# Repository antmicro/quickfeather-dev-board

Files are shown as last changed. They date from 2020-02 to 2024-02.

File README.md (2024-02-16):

# QuickFeather Development Board

Copyright (c) 2019-2024 [Antmicro](https://www.antmicro.com)

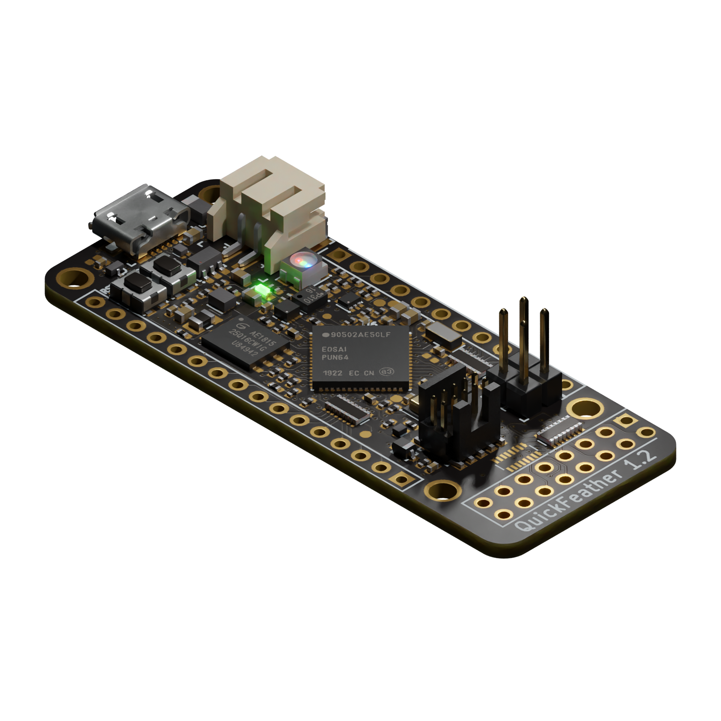
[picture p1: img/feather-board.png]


## Overview

This project contains open hardware design files for the [QuickFeather development board](https://www.quicklogic.com/products/eos-s3/quickfeather-development-kit/) based on the QuickLogic [EOS S3 Sensor Processing Platform](https://www.quicklogic.com/products/eos-s3/).
The design files were created by [Antmicro](https://www.antmicro.com) in cooperation with [QuickLogic](https://www.quicklogic.com/).
The board has been designed to keep compatibility with the [Adafruit Feather](https://learn.adafruit.com/adafruit-feather/feather-specification) ecosystem of evaluation boards.
This allows the user to explore functionalities of the EOS S3 platform.

### Project structure:

The main directory contains the KiCad design files, LICENSE and README.
The remaining files are stored in the following directories:

* ``img`` - contains graphics for this README
* ``doc`` - contains generated schematics and other documentation
* ``lib`` - contains KiCad component library

## Key features

* QuickLogic EOS S3 Processing Platform
* [mCube MC3635](https://www.memsic.com/Public/Uploads/uploadfile/files/20220119/MC3635Datasheet.pdf) accelerometer
* [Infineon DPS310](https://www.infineon.com/dgdl/Infineon-DPS310-DataSheet-v01_01-EN.pdf?fileId=5546d462576f34750157750826c42242) pressure sensor
* [Infineon IM69D130](https://www.infineon.com/dgdl/Infineon-IM69D130-DS-v01_00-EN.pdf?fileId=5546d462602a9dc801607a0e46511a2e) MEMS microphone 
* 16Mbit of on-board [flash memory](https://www.gigadevice.com.cn/Public/Uploads/uploadfile/files/20220714/DS-00086-GD25Q16C-Rev3.2.pdf)
* User button and RGB LED
* Powered from USB or a single Li-Po battery
* Integrated [battery charger](http://ww1.microchip.com/downloads/en/DeviceDoc/20001984g.pdf)
* USB data signals tied to programmable logic
* IO signals break-routed into general purpose pinheads
* Compatible with standard 0.1" breadboards

## Development ecosystem

### Simulation

The board is supported in [Renode](https://renode.io/), the open source simulation framework by Antmicro - you can run a virtual copy of this hardware for software development purposes on your PC. A link to the relevant demo script is provided in Renode's [supported boards section](https://renode.readthedocs.io/en/latest/introduction/supported-boards.html).

## License

This project is licensed under the [CC BY-SA 4.0 DEED](LICENSE) license.

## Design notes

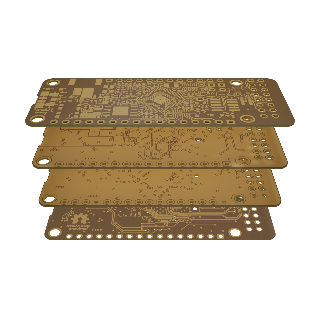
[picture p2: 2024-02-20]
assets/previews/layer1_thumbnail.webp

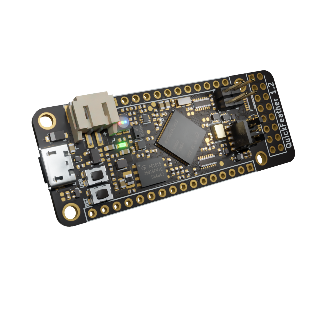
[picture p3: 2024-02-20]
assets/previews/leftT_thumbnail.png

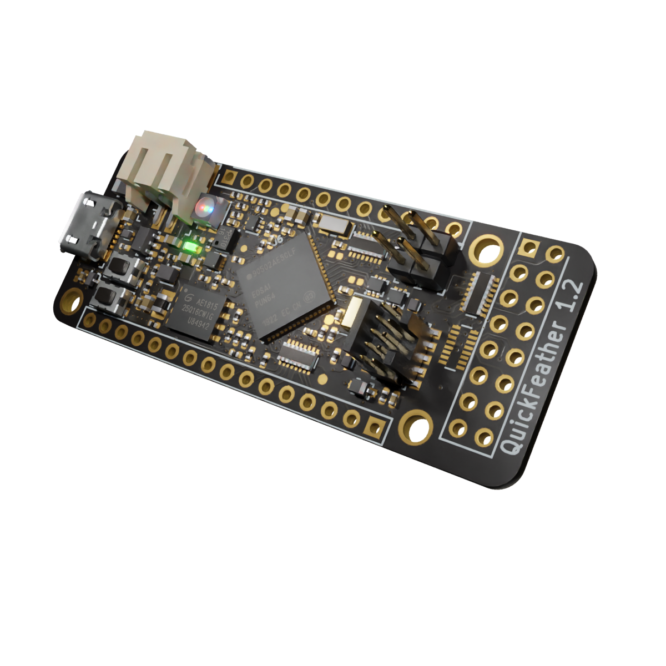
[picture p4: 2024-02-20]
assets/previews/rightT.webp

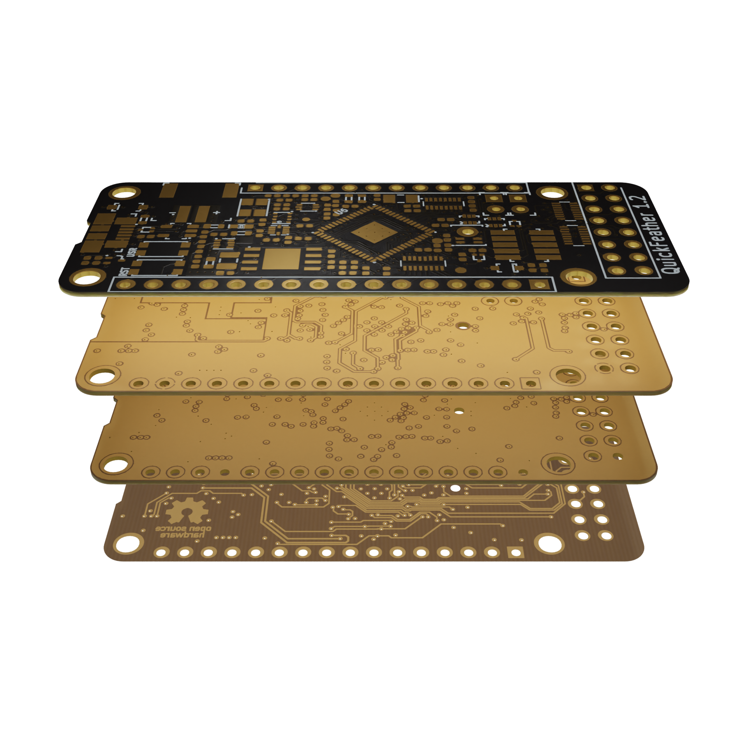
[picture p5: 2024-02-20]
assets/previews/stackup.png

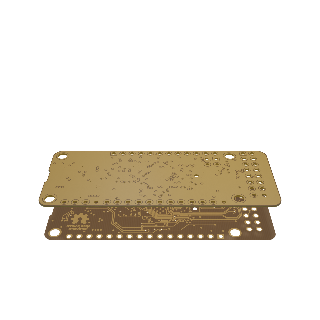
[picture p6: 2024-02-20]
assets/previews/layer3_thumbnail.webp

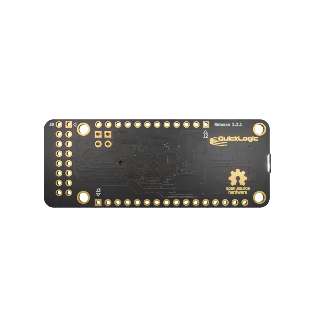
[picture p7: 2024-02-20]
assets/previews/orthoB_thumbnail.webp

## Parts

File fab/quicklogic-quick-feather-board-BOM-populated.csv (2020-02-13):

Reference | Quantity | Value | Footprint | Manufacturer | MPN
C1 C14 C16 C2 C5 | 5 | C_4u7_0603 | 0603-cap | TDK | C1608X5R1V475M080AC
C10 C11 C12 C13 C15 C17 C18 C8 C9 | 9 | C_100n_0402_6V3 | 0402-cap | Walsin | 0402X104K6R3CT
C3 | 1 | C_100p_0402 | 0402-cap | WALSIN | 0402N101J500CT
C4 | 1 | C_22u_0603 | 0603-cap | MURATA | GRM188R60J226MEA0D
C6 C7 | 2 | C_12p_0402 | 0402-cap | TDK | CGA2B2C0G1H120J050BA
D1 | 1 | MBR0520LT1G | SOD-123 | ON Semiconductor | MBR0520LT1G
D11 D3 D5 | 3 | TPD2EUSB30DRTR | SOT-3 | Texas Instruments | TPD2EUSB30DRTR
D2 | 1 | LG_L29K-G2J1-24-Z | LED_0603 | OSRAM Opto Semiconductors Inc. | LG L29K-G2J1-24-Z
D4 | 1 | ASMB-MTB1-0A3A2 | LED-PLCC4_3.2x2.8mm_B | Broadcom | ASMB-MTB1-0A3A2
D6 | 1 | SD05C.TCT | SOD-323-SD05 | Semtec | SD05C.TCT
IC1 | 1 | EOS-S3-QFN | QFN-64_8.5x8.5_EOS |  |  | Delivered by Quicklogic
J1 J7 | 2 | 61300211121 | PinHeader_1x2_P2.54_Drill0.9mm | Wurth Electronic | 61300211121
J4 | 1 | S2B-PH-SM4-TB_LF__SN_ | PinHeader_2x1mm_P2mm_SMD_RA | JST Sales America Inc. | S2B-PH-SM4-TB(LF)(SN)
J5 | 1 | 0473460001 | USB_Micro_B_Female_0473460001 | Molex | 0473460001
J6 | 1 | FTSH-105-01-L-DV-K | PinHeader_2x5_P1.27_SMD | Samtec Inc. | FTSH-105-01-L-DV-K
L1 | 1 | DFE201610E-R47M=P2 | 0806 | Murata | DFE201610E-R47M=P2
MIC1 | 1 | IM69D130 | IM69D130 | Infineon | IM69D130
Q1 | 1 | NX3008CBKV | SOT-563 | Nexperia | NX3008CBKV
Q2 Q3 | 2 | 2N7002PV | SOT-563 | Nexperia | 2N7002PV
R1 R12 R17 R5 | 4 | R_100k_0402 | 0402-res | VISHAY | CRCW0402100KFKEDHP
R10 R14 R15 R19 R23 R31 R32 R34 R37 R6 R8 | 11 | R_10k_0402 | 0402-res | VISHAY | CRCW040210K0FKEDHP
R11 R28 R29 R38 R39 R40 R7 | 7 | R_22R_0402 | 0402-res | VISHAY | CRCW040222R0FKED
R13 R24 R26 | 3 | R_100R_0402 | 0402-res | BOURNS | CR0402-FX-1000GLF
R16 | 1 | R_200k_0402 | 0402-res | YAGEO_(PHYCOMP) | RC0402FR-07200KL
R18 R2 R20 | 3 | R_4k7_0402 | 0402-res | PANASONIC_ELECTRONIC_COMPONENTS | ERJ2GEJ472X
R25 | 1 | R_220R_0402 | 0402-res | Stackpole Electronics Inc | RMCF0402JT220R
R3 R9 | 2 | R_1k5_0402 | 0402-res | PANASONIC_ELECTRONIC_COMPONENTS | ERJ2RKF1501X
R30 R33 R41 | 3 | EXB2HV220JV | R_Array_Convex_8x0602 | Panasonic | EXB2HV220JV
R4 | 1 | R_453k_0402 | 0402-res | VISHAY | CRCW0402453KFKED
S1 S2 | 2 | KMR2 | SW_SPST_4.2x2.8 | C&K Components | KMR211NGLFS
U1 | 1 | TPS62821DLCR | QFN-8_2x1mm | Texas Instruments | TPS62821DLCR
U2 | 1 | MCP73831T-2ACI_OT | SOT-753 | Microchip Technology | MCP73831T-2ACI/OT
U3 | 1 | GD25Q16CWIGR | GD25Q16CWIG | GigaDevice | GD25Q16CWIGR
U4 | 1 | DPS310 | PG-VLGA-8-2 | Infineon | DPS310
U5 | 1 | MC3635 | MC3635 | mCube | MC3635
X1 | 1 | ECS-_327-12_5-34B-TR | SMD-2_3.2x1.5mm | ECS Inc. | ECS-.327-12.5-34B-TR

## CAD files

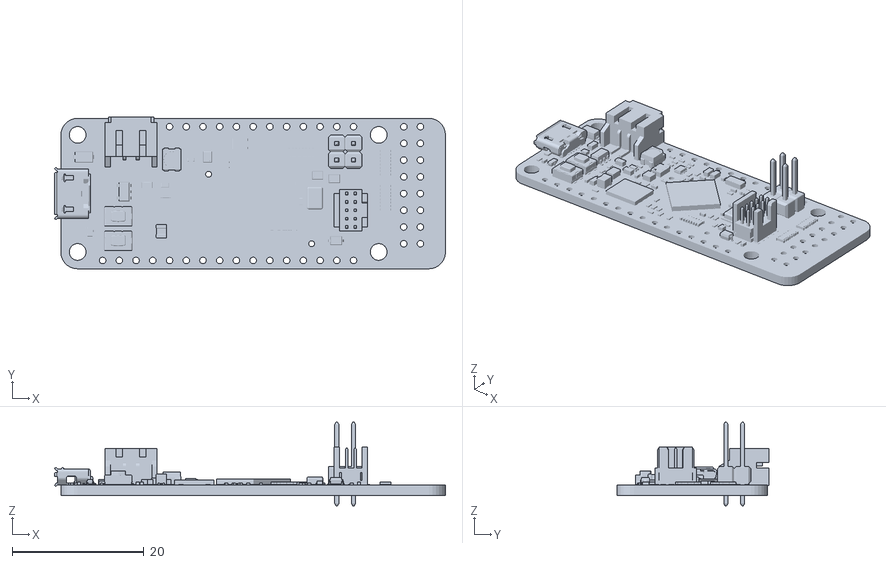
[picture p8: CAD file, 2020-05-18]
3d-model/quickfeather-board.stl
59.4 x 23.0 x 12.7

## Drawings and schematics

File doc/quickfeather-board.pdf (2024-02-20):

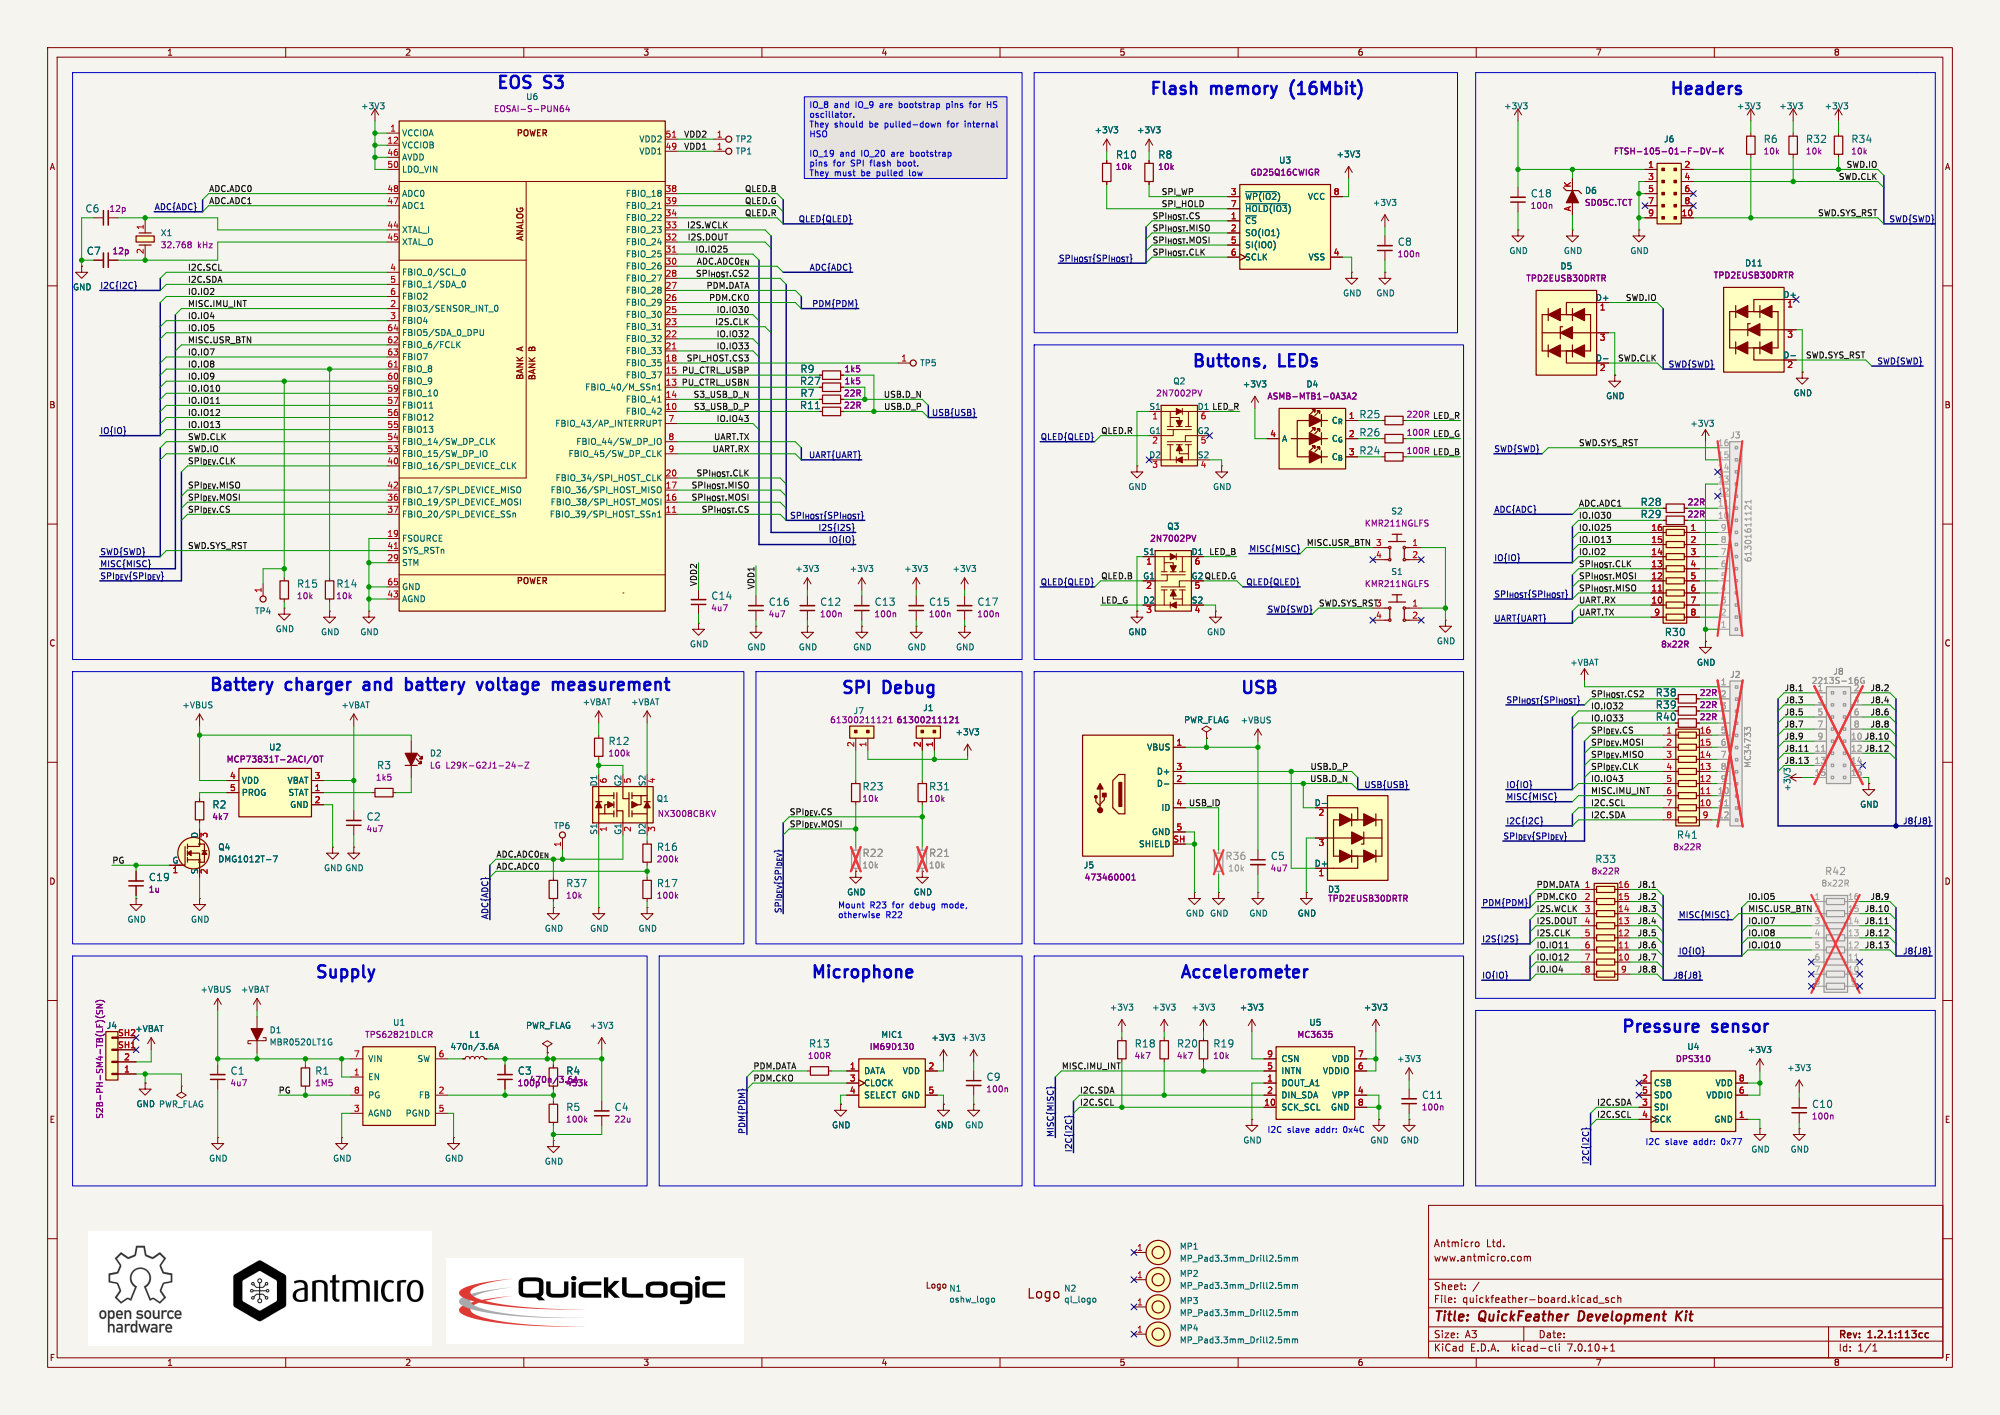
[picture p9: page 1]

IO_19 and IO_20 are bootstrap
pins for SPI flash boot. They must be pulled low

USB.D_P USB{USB} USB.D_N

SPI_{HOST}{SPI_{HOST}} ADC.ADC1 SPI_{HOST}.CLK
J8.7 ADC{ADC}

ID 4 GND 5 SHIELD SH

Id: 1/1 Title: QuickFeather Development Kit File: quickfeather-board.kicad_sch Sheet: / www.antmicro.com

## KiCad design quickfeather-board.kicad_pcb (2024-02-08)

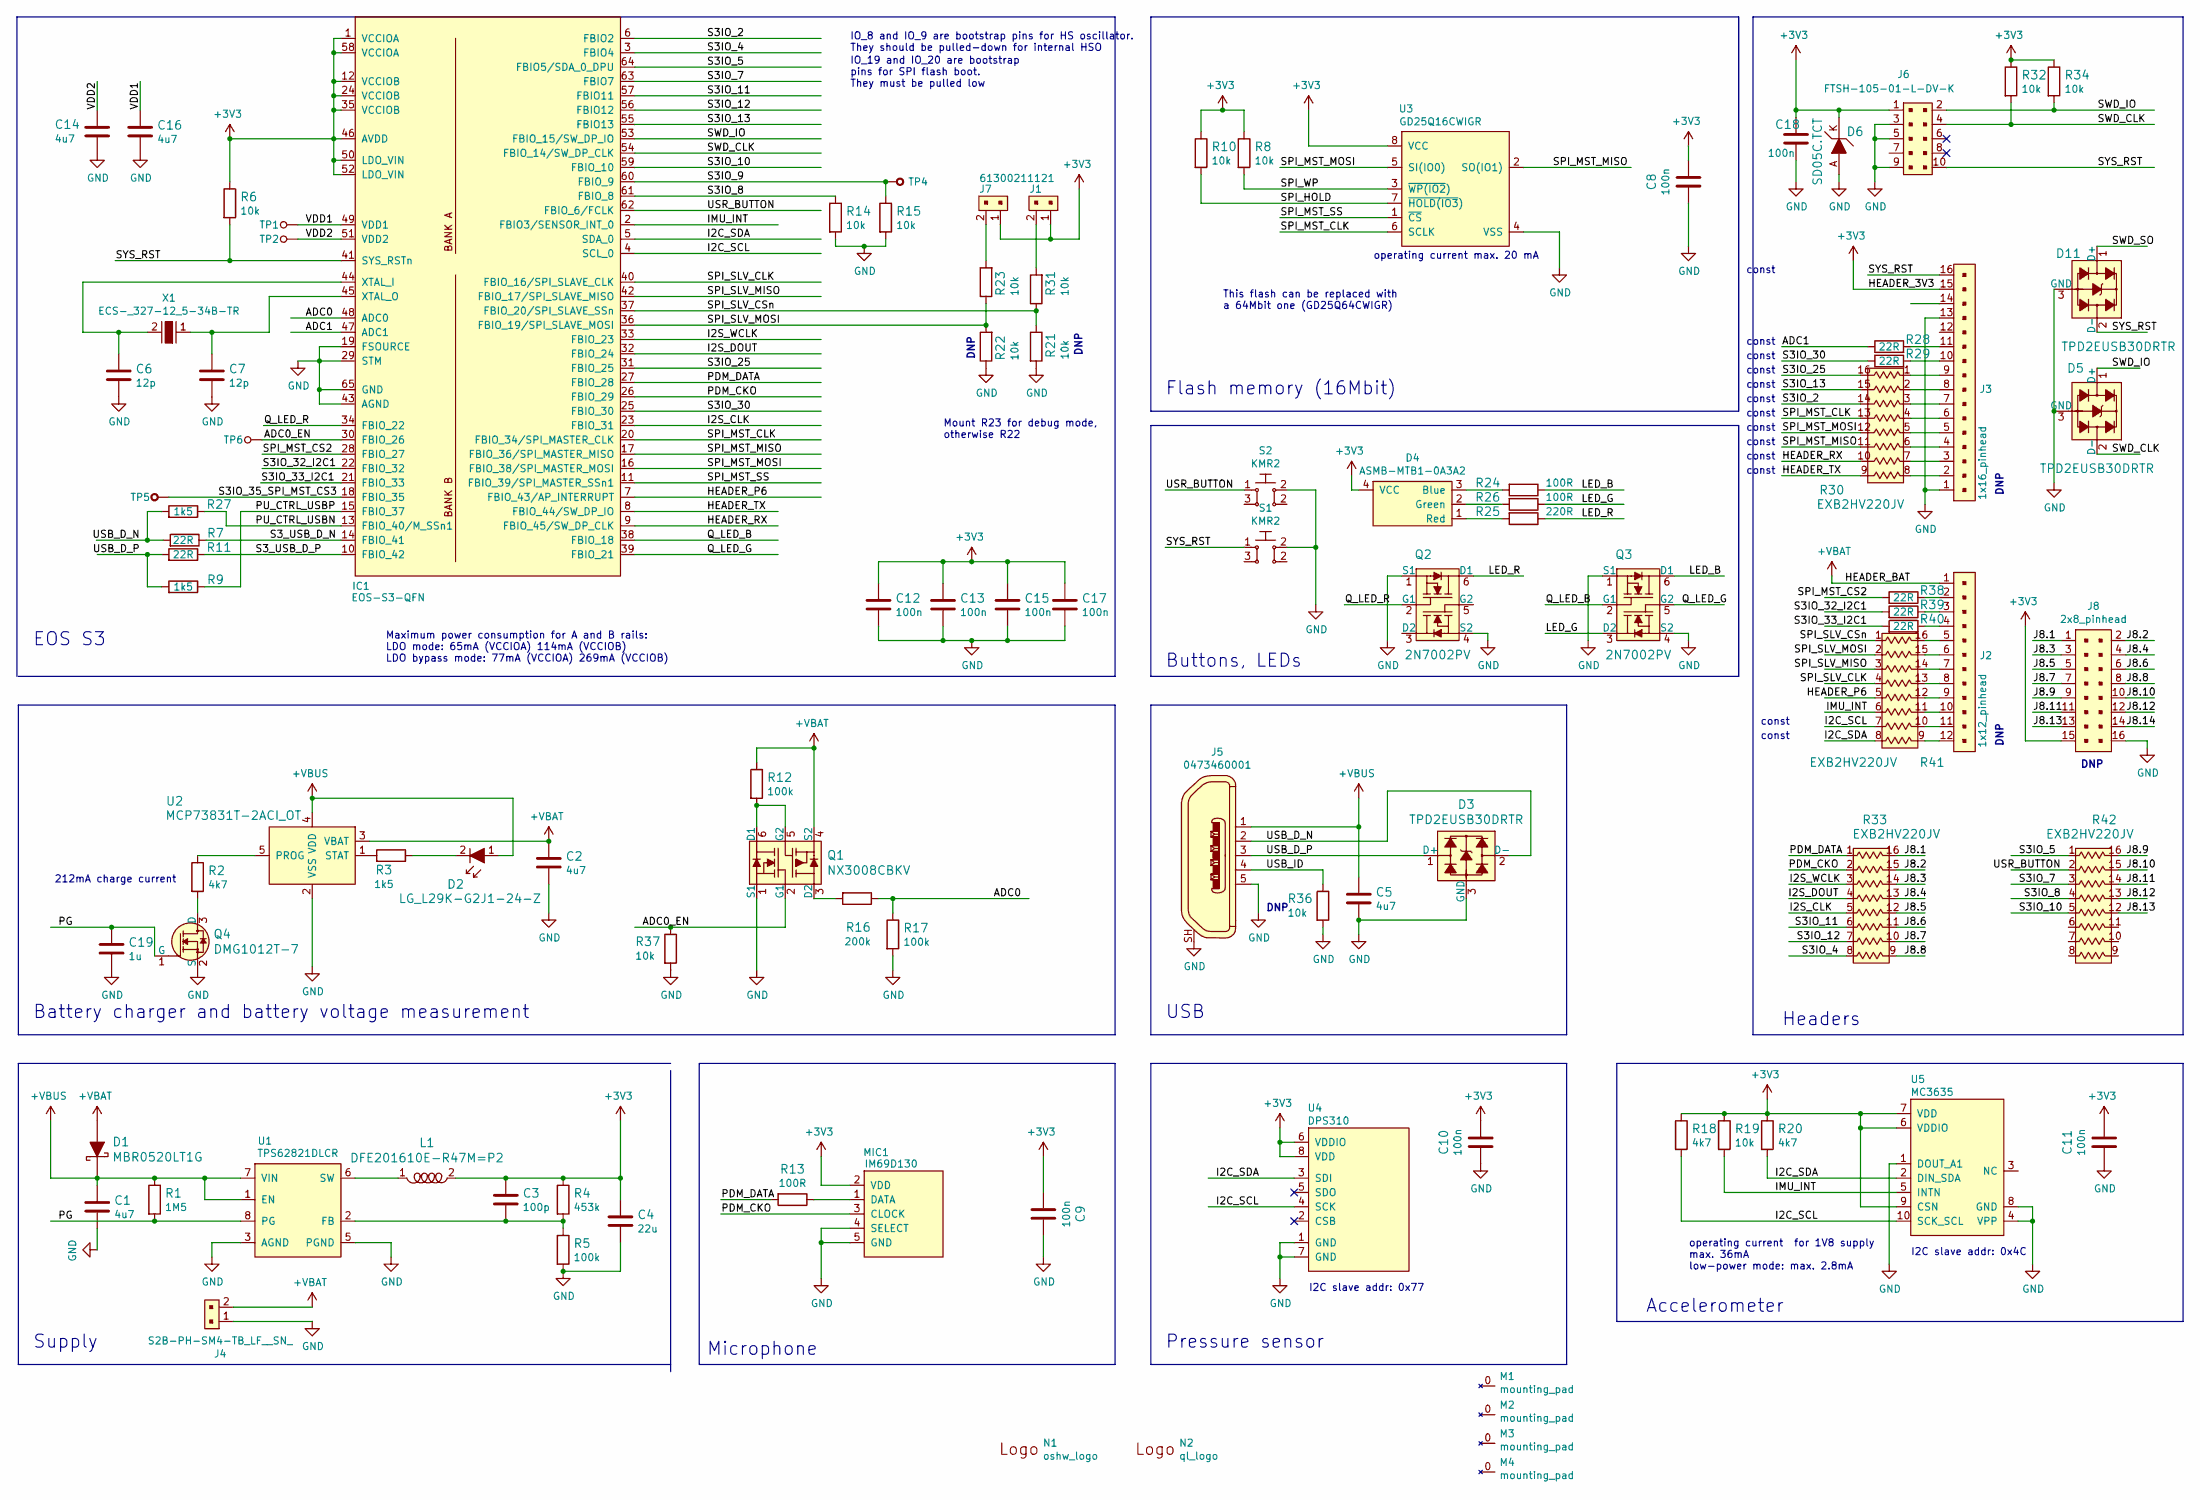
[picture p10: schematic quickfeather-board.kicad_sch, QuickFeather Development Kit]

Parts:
C1, C2, C5, C14, C16: C_4u7_0603; 0603-cap; MPN C1608X5R1V475M080AC
C3: C_100p_0402; 0402-cap; MPN 0402N101J500CT
C4: C_22u_0603; 0603-cap; MPN GRM188R60J226MEA0D
C6, C7: C_12p_0402; 0402-cap; MPN CGA2B2C0G1H120J050BA
C8, C9, C10, C11, C12, C13, C15, C17, C18: C_100n_0402_6V3; 0402-cap; MPN 0402X104K6R3CT
C19: C_1u_0402; 0402-cap; MPN C1005X6S1A105K050BC
D1: MBR0520LT1G; SOD-123; MPN MBR0520LT1G
D2: LG_L29K-G2J1-24-Z; LED_0603; MPN LG L29K-G2J1-24-Z
D3, D5, D11: TPD2EUSB30DRTR; SOT-3; MPN TPD2EUSB30DRTR
D4: ASMB-MTB1-0A3A2; LED-PLCC4_3.2x2.8mm_B; MPN UHD1110-FKA
D6: SD05C.TCT; SOD-323-SD05; MPN SD05C.TCT
IC1: EOS-S3-QFN; QFN-64_8.5x8.5_EOS; MPN EOSA1-S-PUN64
J1, J7: 61300211121; PinHeader_1x2_P2.54_Drill0.9mm; MPN 61300211121
J2: 1x12_pinhead; MPN MC34733
J3: 1x16_pinhead; MPN 61301611121
J4: S2B-PH-SM4-TB_LF__SN_; PinHeader_2x1mm_P2mm_SMD_RA; MPN S2B-PH-SM4-TB(LF)(SN)
J5: 0473460001; USB_Micro_B_Female_0473460001; MPN 0473460001
J6: FTSH-105-01-L-DV-K; PinHeader_2x5_P1.27_SMD; MPN FTSH-105-01-L-DV-K
J8: 2x8_pinhead; MPN 2213S-16G
L1: DFE201610E-R47M=P2; 0806; MPN DFE201610E-R47M=P2
M1, M2, M3, M4: mounting_pad; MPAD
MIC1: IM69D130; MPN IM69D130
N1: oshw_logo; oshw-logo
N2: ql_logo; LOGO
Q1: NX3008CBKV; SOT-563; MPN NX3008CBKV
Q2, Q3: 2N7002PV; SOT-563; MPN 2N7002PV
Q4: DMG1012T-7; SOT-523; MPN DMG1012T-7
R1: R_1M5_0402; 0402-res; MPN MCWR04W1504FTL
R2, R18, R20: R_4k7_0402; 0402-res; MPN ERJ2GEJ472X
R3, R9, R27: R_1k5_0402; 0402-res; MPN ERJ2RKF1501X
R4: R_453k_0402; 0402-res; MPN CRCW0402453KFKED
R5, R12, R17: R_100k_0402; 0402-res; MPN CRCW0402100KFKEDHP
R6, R8, R10, R14, R15, R19, R21, R22, R23, R31, R32, R34, R36, R37: R_10k_0402; 0402-res; MPN CRCW040210K0FKEDHP
R7, R11, R28, R29, R38, R39, R40: R_22R_0402; 0402-res; MPN CRCW040222R0FKED
R13, R24, R26: R_100R_0402; 0402-res; MPN CR0402-FX-1000GLF
R16: R_200k_0402; 0402-res; MPN RC0402FR-07200KL
R25: R_220R_0402; 0402-res; MPN RMCF0402JT220R
R30, R33, R41, R42: EXB2HV220JV; R_Array_Convex_8x0602; MPN EXB2HV220JV
S1, S2: KMR2; SW_SPST_4.2x2.8; MPN KMR211NGLFS
TP1, TP2, TP6: TP_SMD1MM; Testpoint_smd_1mm; MPN N/A
TP4, TP5: TP_THT; Testpoint_THT_Drill0.9mm; MPN N/A
U1: TPS62821DLCR; QFN-8_2x1mm; MPN TPS62821DLCR
U2: MCP73831T-2ACI_OT; SOT-753; MPN MCP73831T-2ACI/OT
U3: GD25Q16CWIGR; GD25Q16CWIG; MPN GD25Q16CWIGR
U4: DPS310; PG-VLGA-8-2; MPN DPS310
U5: MC3635; MPN MC3635
X1: ECS-_327-12_5-34B-TR; SMD-2_3.2x1.5mm; MPN ECS-.327-12.5-34B-TR

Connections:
+3V3: C3.1, C4.1, C8.1, C9.2, C10.1, C11.1, C12.1, C13.1, C15.1, C17.1, C18.1, D4.4 (VCC), D6.K, IC1.1 (VCCIOA), IC1.12 (VCCIOB), IC1.24 (VCCIOB), IC1.35 (VCCIOB), IC1.46 (AVDD), IC1.50 (LDO_VIN), IC1.52 (LDO_VIN), IC1.58 (VCCIOA), J1.1, J3.15, J6.1, J7.1, J8.15, L1.2, MIC1.2 (VDD), R4.1, R6.1, R8.1, R10.1, R18.1, R19.1, R20.1, R32.1, R34.1, U3.8 (VCC), U4.6 (VDDIO), U4.8 (VDD), U5.6 (VDDIO), U5.7 (VDD), U5.9 (CSN)
+VBAT: C2.1, D1.A, J2.1, J4.2, Q1.4 (S2), R12.1, U2.3 (VBAT)
+VBUS: C1.1, C5.1, D1.K, D2.1, J5.1, R1.1, U1.1 (EN), U1.7 (VIN), U2.4 (VDD)
/ADC0: IC1.48 (ADC0), R16.1, R17.1
/ADC0_EN: IC1.30 (FBIO_26), Q1.2 (G1), R37.1, TP6.1
/ADC1: IC1.47 (ADC1), R28.1
/HEADER_P6: IC1.7 (FBIO_43/AP_INTERRUPT), R41.5
/HEADER_RX: IC1.9 (FBIO_45/SW_DP_CLK), R30.10
/HEADER_TX: IC1.8 (FBIO_44/SW_DP_IO), R30.9
/I2C_SCL: IC1.4 (SCL_0), R18.2, R41.7, U4.4 (SCK), U5.10 (SCK_SCL)
/I2C_SDA: IC1.5 (SDA_0), R20.2, R41.8, U4.3 (SDI), U5.2 (DIN_SDA)
/I2S_CLK: IC1.23 (FBIO_31), R33.5
/I2S_DOUT: IC1.32 (FBIO_24), R33.4
/I2S_WCLK: IC1.33 (FBIO_23), R33.3
/IMU_INT: IC1.2 (FBIO3/SENSOR_INT_0), R19.2, R41.6, U5.5 (INTN)
/J8.1: J8.1, R33.16
/J8.2: J8.2, R33.15
/J8.3: J8.3, R33.14
/J8.4: J8.4, R33.13
/J8.5: J8.5, R33.12
/J8.6: J8.6, R33.11
/J8.7: J8.7, R33.10
/J8.8: J8.8, R33.9
/J8.9: J8.9, R42.16
/J8.10: J8.10, R42.15
/J8.11: J8.11, R42.14
/J8.12: J8.12, R42.13
/J8.13: J8.13, R42.12
/J8.14: J8.14
/LED_B: Q3.6 (D1), R24.1
/LED_G: Q3.3 (D2), R26.1
/LED_R: Q2.6 (D1), R25.1
/PDM_CKO: IC1.26 (FBIO_29), MIC1.3 (CLOCK), R33.2
/PDM_DATA: IC1.27 (FBIO_28), R13.2, R33.1
/PG: C19.1, Q4.1 (G), R1.2, U1.8 (PG)
/PU_CTRL_USBN: IC1.13 (FBIO_40/M_SSn1), R27.1
/PU_CTRL_USBP: IC1.15 (FBIO_37), R9.1
/Q_LED_B: IC1.38 (FBIO_18), Q3.2 (G1)
/Q_LED_G: IC1.39 (FBIO_21), Q3.5 (G2)
/Q_LED_R: IC1.34 (FBIO_22), Q2.2 (G1)
/S3IO_2: IC1.6 (FBIO2), R30.14
/S3IO_4: IC1.3 (FBIO4), R33.8
/S3IO_5: IC1.64 (FBIO5/SDA_0_DPU), R42.1
/S3IO_7: IC1.63 (FBIO7), R42.3
/S3IO_8: IC1.61 (FBIO_8), R14.1, R42.4
/S3IO_9: IC1.60 (FBIO_9), R15.1, TP4.1
/S3IO_10: IC1.59 (FBIO_10), R42.5
/S3IO_11: IC1.57 (FBIO11), R33.6
/S3IO_12: IC1.56 (FBIO12), R33.7
/S3IO_13: IC1.55 (FBIO13), R30.15
/S3IO_25: IC1.31 (FBIO_25), R30.16
/S3IO_30: IC1.25 (FBIO_30), R29.1
/S3IO_32_I2C1: IC1.22 (FBIO_32), R39.2
/S3IO_33_I2C1: IC1.21 (FBIO_33), R40.2
/S3IO_35_SPI_MST_CS3: IC1.18 (FBIO_35), TP5.1
/S3_USB_D_N: IC1.14 (FBIO_41), R7.1
/S3_USB_D_P: IC1.10 (FBIO_42), R11.1
/SPI_HOLD: R10.2, U3.7 (~HOLD(IO3))
/SPI_MST_CLK: IC1.20 (FBIO_34/SPI_MASTER_CLK), R30.13, U3.6 (SCLK)
/SPI_MST_CS2: IC1.28 (FBIO_27), R38.2
/SPI_MST_MISO: IC1.17 (FBIO_36/SPI_MASTER_MISO), R30.11, U3.2 (SO(IO1))
/SPI_MST_MOSI: IC1.16 (FBIO_38/SPI_MASTER_MOSI), R30.12, U3.5 (SI(IO0))
/SPI_MST_SS: IC1.11 (FBIO_39/SPI_MASTER_SSn1), U3.1 (~CS)
/SPI_SLV_CLK: IC1.40 (FBIO_16/SPI_SLAVE_CLK), R41.4
/SPI_SLV_CSn: IC1.37 (FBIO_20/SPI_SLAVE_SSn), R21.1, R31.1, R41.1
/SPI_SLV_MISO: IC1.42 (FBIO_17/SPI_SLAVE_MISO), R41.3
/SPI_SLV_MOSI: IC1.36 (FBIO_19/SPI_SLAVE_MOSI), R22.2, R23.1, R41.2
/SPI_WP: R8.2, U3.3 (~WP(IO2))
/SWD_CLK: D5.2 (D-), IC1.54 (FBIO_14/SW_DP_CLK), J6.4, R32.2
/SWD_IO: D5.1 (D+), IC1.53 (FBIO_15/SW_DP_IO), J6.2, R34.2
/SWD_SO: D11.1 (D+)
/SYS_RST: D11.2 (D-), IC1.41 (SYS_RSTn), J3.16, J6.10, R6.2, S1.1
/USB_D_N: D3.2 (D-), J5.2, R7.2, R27.2
/USB_D_P: D3.1 (D+), J5.3, R9.2, R11.2
/USB_ID: J5.4, R36.1
/USR_BUTTON: IC1.62 (FBIO_6/FCLK), R42.2, S2.1
/VDD1: C16.1, IC1.49 (VDD1), TP1.1
/VDD2: C14.1, IC1.51 (VDD2), TP2.1
GND: C1.2, C2.2, C4.2, C5.2, C6.2, C7.2, C8.2, C9.1, C10.2, C11.2, C12.2, C13.2, C14.2, C15.2, C16.2, C17.2, C18.2, C19.2, D3.3 (GND), D5.3 (GND), D6.A, D11.3 (GND), IC1.19 (FSOURCE), IC1.29 (STM), IC1.43 (AGND), IC1.65 (GND), J3.1, J3.13, J4.1, J5.5, J5.SH, J6.3, J6.5, J6.9, J8.16, MIC1.4 (SELECT), MIC1.5 (GND), Q1.1 (S1), Q2.1 (S1), Q2.4 (S2), Q3.1 (S1), Q3.4 (S2), Q4.2 (S), R5.2, R14.2, R15.2, R17.2, R21.2, R22.1, R36.2, R37.2, S1.2, S2.2, U1.3 (AGND), U1.5 (PGND), U2.2 (VSS), U3.4 (VSS), U4.1 (GND), U4.7 (GND), U5.1 (DOUT_A1), U5.4 (VPP), U5.8 (GND)
unnamed: C3.2, R4.2, R5.1, U1.2 (FB)
unnamed: C6.1, IC1.44 (XTAL_I), X1.2
unnamed: C7.1, IC1.45 (XTAL_O), X1.1
unnamed: D2.2, R3.1
unnamed: D4.1 (Red), R25.2
unnamed: D4.2 (Green), R26.2
unnamed: D4.3 (Blue), R24.2
unnamed: J1.2, R31.2
unnamed: J2.2, R38.1
unnamed: J2.3, R39.1
unnamed: J2.4, R40.1
unnamed: J2.5, R41.16
unnamed: J2.6, R41.15
unnamed: J2.7, R41.14
unnamed: J2.8, R41.13
unnamed: J2.9, R41.12
unnamed: J2.10, R41.11
unnamed: J2.11, R41.10
unnamed: J2.12, R41.9
unnamed: J3.2, R30.8
unnamed: J3.3, R30.7
unnamed: J3.4, R30.6
unnamed: J3.5, R30.5
unnamed: J3.6, R30.4
unnamed: J3.7, R30.3
unnamed: J3.8, R30.2
unnamed: J3.9, R30.1
unnamed: J3.10, R29.2
unnamed: J3.11, R28.2
unnamed: J7.2, R23.2
unnamed: L1.1, U1.6 (SW)
unnamed: MIC1.1 (DATA), R13.1
unnamed: Q1.3 (D2), R16.2
unnamed: Q1.5 (G2), Q1.6 (D1), R12.2
unnamed: Q4.3 (D), R2.2
unnamed: R2.1, U2.5 (PROG)
unnamed: R3.2, U2.1 (STAT)

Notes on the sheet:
Battery charger and battery voltage measurement
const
Pressure sensor
DNP
operating current max. 20 mA
USB
IO_19 and IO_20 are bootstrap pins for SPI flash boot. They must be pulled low
Supply
Microphone
Headers
This flash can be replaced with a 64Mbit one (GD25Q64CWIGR)
212mA charge current
EOS S3
I2C slave addr: 0x4C
I2C slave addr: 0x77
Flash memory (16Mbit)
Buttons, LEDs
Mount R23 for debug mode, otherwise R22
Maximum power consumption for A and B rails: LDO mode: 65mA (VCCIOA) 114mA (VCCIOB) LDO bypass mode: 77mA (VCCIOA) 269mA (VCCIOB)
IO_8 and IO_9 are bootstrap pins for HS oscillator. They should be pulled-down for internal HSO
Accelerometer
operating current for 1V8 supply max. 36mA low-power mode: max. 2.8mA

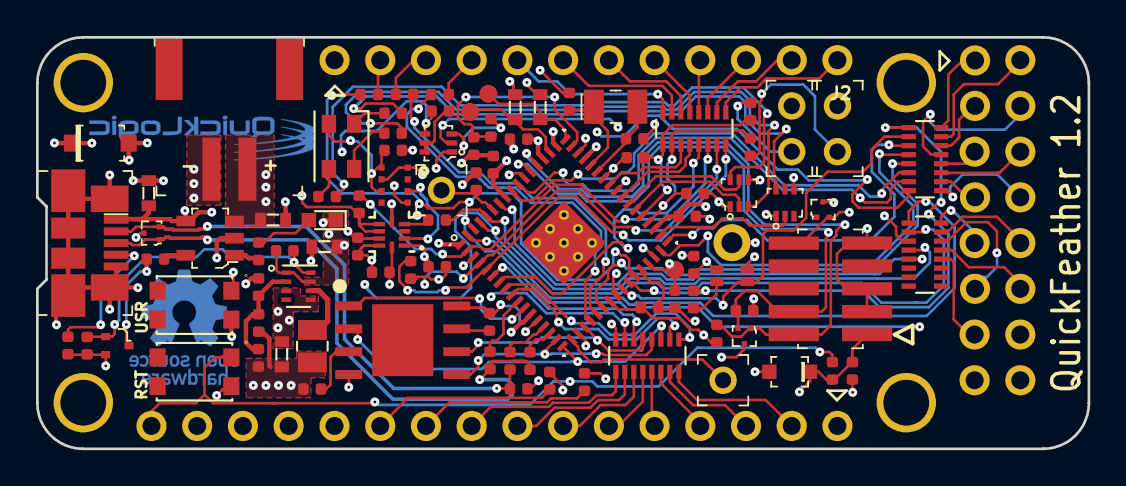
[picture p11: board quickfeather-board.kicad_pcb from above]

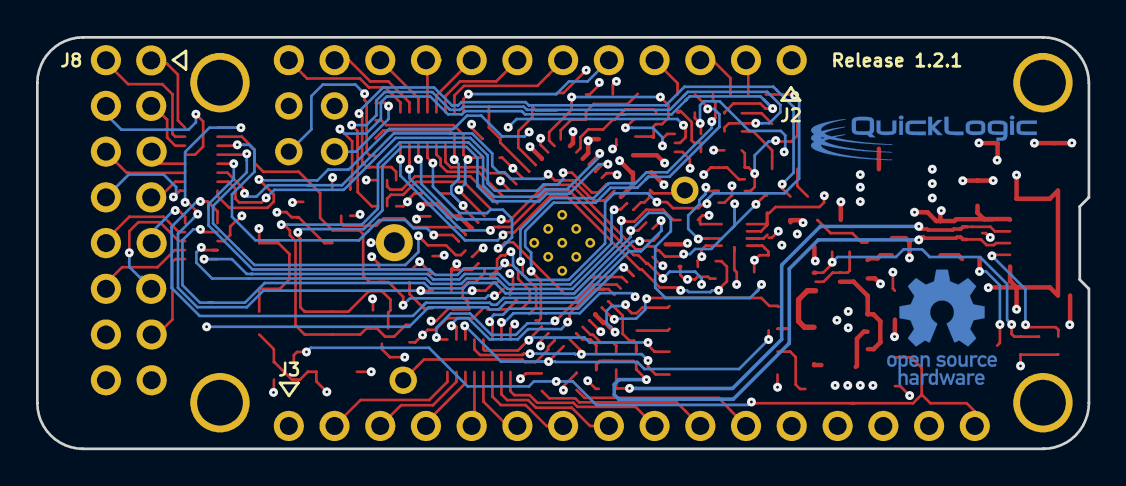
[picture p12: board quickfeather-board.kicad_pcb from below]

Board: 4 copper layers, 58.4 x 22.9 mm, 101 parts (2 on the bottom side), 114 nets.

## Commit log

2019-11-05 added project files, board file with defined outline
    [quicklogic-quick-feather-board.kicad_pcb, quicklogic-quick-feather-board.sch]
2020-02-13 Added power supply circuits
    [quicklogic-quick-feather-board.kicad_pcb, quicklogic-quick-feather-board.sch]
2020-02-13 Updated notes on schematic
    [quicklogic-quick-feather-board.sch]
2020-02-13 Added flash memory and 32kHz crystal
    [quicklogic-quick-feather-board.kicad_pcb, quicklogic-quick-feather-board.sch]
2020-02-13 Added gerbers for initial pcb technological analysis
    [quicklogic-quick-feather-board-B_Mask.gbr, quicklogic-quick-feather-board-B_Paste.gbr, quicklogic-quick-feather-board-B_SilkS.gbr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]
2020-02-13 Updated design rules, proposed initial package escape for 42-WLCSP
    [quicklogic-quick-feather-board-B_Mask.gbr, quicklogic-quick-feather-board-B_Paste.gbr, quicklogic-quick-feather-board-B_SilkS.gbr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]
2020-02-13 Updated package escape so we are loosing 1 ball of WLCSP
    [quicklogic-quick-feather-board-B_Mask.gbr, quicklogic-quick-feather-board-B_Paste.gbr, quicklogic-quick-feather-board-B_SilkS.gbr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]
2020-02-13 Added net names to EOS-S3 pins
    [quicklogic-quick-feather-board.sch]
2020-02-13 Package escape implemented with stacked vias
    [quicklogic-quick-feather-board.kicad_pcb]
2020-02-13 Board stackup changed to 6L, added GND+PWR plane
    [quicklogic-quick-feather-board-B_Mask.gbr, quicklogic-quick-feather-board-B_Paste.gbr, quicklogic-quick-feather-board-B_SilkS.gbr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]
2020-02-13 Updated .gitignore, updated board title
    [quicklogic-quick-feather-board.sch]
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2020-02-13 Changed flash memory, connected missing nets, cleanup
    [quicklogic-quick-feather-board.kicad_pcb, quicklogic-quick-feather-board.sch]
2020-02-13 Added IM69D130 microphone to schematics
    [quicklogic-quick-feather-board.kicad_pcb, quicklogic-quick-feather-board.sch]
2020-02-13 Added TVS for USB
    [quicklogic-quick-feather-board.sch]
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2020-02-13 Added power rail symbols
    [quicklogic-quick-feather-board.sch]
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2020-02-13 Added accelerometer and circuit for measuring battery voltage
    [quicklogic-quick-feather-board.kicad_pcb, quicklogic-quick-feather-board.sch]
2020-02-13 Added bootstrap resistors, connected pressure sensor to I2C bus, placed components on PCB
    [quicklogic-quick-feather-board.kicad_pcb, quicklogic-quick-feather-board.sch]
2020-02-13 Added remarks about power consuption, added filtering capactitors for EOS-S3
    [quicklogic-quick-feather-board.sch]
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2020-02-13 Design updated after internal review
    [quicklogic-quick-feather-board.kicad_pcb, quicklogic-quick-feather-board.sch]
2020-02-13 Changes to header, tweaks to LED, added BAT connector
    [quicklogic-quick-feather-board.kicad_pcb, quicklogic-quick-feather-board.sch]
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2020-02-13 Added TBDs to schematics
    [quicklogic-quick-feather-board.kicad_pcb, quicklogic-quick-feather-board.sch]
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2020-02-13 Added pinhead connectors for debug and programming
    [quicklogic-quick-feather-board.kicad_pcb, quicklogic-quick-feather-board.sch]
2020-02-13 Added LED driving transistors
    [quicklogic-quick-feather-board.kicad_pcb, quicklogic-quick-feather-board.sch]
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2020-02-13 Removed prototyping area, updated component placement
    [quicklogic-quick-feather-board.kicad_pcb]
2020-02-13 J2 and J3 flipped to match feather-like pinouts
    [quicklogic-quick-feather-board.sch]
2020-02-13 Changed MPN for buttons, updated 3D models
    [quicklogic-quick-feather-board.kicad_pcb, quicklogic-quick-feather-board.sch]
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2020-02-13 Updated component placement, added 3D models for pin headers
    [quicklogic-quick-feather-board.kicad_pcb]
2020-02-13 Added some MPNs to libraries and updated them on schematic, updated BOM and schematic PDF
    [quicklogic-quick-feather-board.csv, quicklogic-quick-feather-board.kicad_pcb, quicklogic-quick-feather-board.sch]
2020-02-13 Removed HEADER_A5 connection to J6, removed R31 and R33
    [quicklogic-quick-feather-board.sch]
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2020-02-13 Added a 2-pin header to configure bootstrap pins for EOS IC
    [quicklogic-quick-feather-board.sch]
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2020-02-13 Fixed BOM
    [quicklogic-quick-feather-board.csv]
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2020-02-13 Changed jumper to mini jumper + slide switch. Footprint update
    [quicklogic-quick-feather-board.kicad_pcb, quicklogic-quick-feather-board.sch]
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2020-02-13 Early attempt of routing of most crossed lines
    [quicklogic-quick-feather-board.kicad_pcb, quicklogic-quick-feather-board.sch]
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2020-02-13 Swapped signals connected to EOS S3 pin 27 and 28
    [quicklogic-quick-feather-board.kicad_pcb, quicklogic-quick-feather-board.sch]
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2020-02-13 Fixed DRC issues, updated layout
    [quicklogic-quick-feather-board.kicad_pcb, quicklogic-quick-feather-board.sch]
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2020-02-13 Added MPNs for pinheads, updated BOM and schematic PDF
    [quicklogic-quick-feather-board.csv, quicklogic-quick-feather-board.sch]
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2020-02-13 Added gerbers used for making prototypes in rev. 1.0
    [quicklogic-quick-feather-board-B_Mask.gbr, quicklogic-quick-feather-board-B_Paste.gbr, quicklogic-quick-feather-board-B_SilkS.gbr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]
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2020-02-13 Updated footprint for RGB LED. Project revision changed to 1.0.1
    [quicklogic-quick-feather-board.kicad_pcb, quicklogic-quick-feather-board.sch]
2020-02-13 Corrected MPN for pinhead
    [quicklogic-quick-feather-board-BOM-all.csv, quicklogic-quick-feather-board-BOM-by-layer.csv, quicklogic-quick-feather-board-BOM-populated.csv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]
2020-02-13 Fixed SOT-563 footprint
    [quicklogic-quick-feather-board.kicad_pcb]
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2020-02-13 Modified MC3635 paste layer pattern, tweaked layout around MC3635
    [quicklogic-quick-feather-board.kicad_pcb]
2020-02-13 Minor fix in PCB file
    [quicklogic-quick-feather-board.kicad_pcb]
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2020-02-13 Minor fixes
    [quicklogic-quick-feather-board.kicad_pcb]
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2020-02-13 Minor fix
    [quick-feather-board.sch]
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2020-03-06 Updated PCB layout for charger with delayed startup
    [quick-feather-board.kicad_pcb, quick-feather-board.sch]
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2020-03-13 Corrected IO_27 to IO_30
    [quick-feather-board.kicad_pcb, quick-feather-board.sch]
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2024-02-16 [#54927] Update components on PCB to standardized versions
    [quickfeather-board.kicad_sch]
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2024-02-16 [#54927] Fix ERC
    [quickfeather-board.kicad_sch]
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2024-02-16 [#54927] Fix DRC
    [quickfeather-board.kicad_sch]
2024-02-16 [#54927] Fix 3d model of 1x16 pin head
2024-02-16 [#54927] Fix silkscreen
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2024-02-16 [#54927] Fix DNP
    [quickfeather-board.kicad_sch]
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2024-02-16 [#54927] Convert README to MD, update board image, fix links
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
